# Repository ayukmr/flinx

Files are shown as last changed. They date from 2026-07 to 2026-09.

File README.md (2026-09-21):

# flinx



nRF52833-based low-profile 40% keyboard.

The board uses Kailh Choc V2 switches, and purposely doesn't include any stabilizers.
The PCB fits directly inside the case and is mounted with four screws.
A USB-C port on the side is used for charging, and a switch turns the board on/off.
Once turned on, the keyboard pairs over Bluetooth to send keystrokes.

This is intended as a small board mostly for travel, and as a low-profile version of the Monokei Neko.

## Schematic



## PCB



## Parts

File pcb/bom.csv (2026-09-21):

Reference | Qty | Value | Footprint | DigiKey Part # | Link
ANT1 | 1 | 451-00001 | Project:45100001 | 451-00001CT-ND | https://www.digikey.com/en/products/detail/ezurio/451-00001/9489361
C1 | 1 | 12 pF | Capacitor_SMD:C_0603_1608Metric | 311-1059-1-ND | https://www.digikey.com/en/products/detail/yageo/CC0603JRNPO9BN120/302793
C2 | 1 | 10 pF | Capacitor_SMD:C_0603_1608Metric | 311-4025-1-ND | https://www.digikey.com/en/products/detail/yageo/CC0603KRNPO9BN100/5883701
C3 | 1 | 100 nF | Capacitor_SMD:C_0603_1608Metric | 311-1343-1-ND | https://www.digikey.com/en/products/detail/yageo/CC0603ZRY5V9BB104/2103081
C4,C5,C6 | 3 | 10 uF | Capacitor_SMD:C_0603_1608Metric | 311-1781-1-ND | https://www.digikey.com/en/products/detail/yageo/CC0603KRX5R5BB106/5195190
D1,D2,D3,D4,D5,D6,D7,D8,D9,D10,D11,D12,D13,D14,D15,D16,D17,D18,D19,D20,D21,D22,D23,D24,D25,D26,D27,D28,D29,D30,D31,D32,D33,D34,D35,D36,D37,D38,D39,D40,D41,D42,D43,D44,D45,D46,D47,D48 | 48 | D | Diode_SMD:D_SOD-523 | 1655-1N4148WCT-ND | https://www.digikey.com/en/products/detail/smc-diode-solutions/1N4148W/6022450
J1 | 1 | USB_C_Receptacle_USB2.0_14P | Connector_USB:USB_C_Receptacle_JAE_DX07S016JA1R1500 | 670-DX07S016JA3R1500CT-ND | https://www.digikey.com/en/products/detail/jae-electronics/DX07S016JA3R1500/12354006
R1,R2 | 2 | 22 Ω | Resistor_SMD:R_0603_1608Metric | 311-22.0HRCT-ND | https://www.digikey.com/en/products/detail/yageo/RC0603FR-0722RL/727055
R3,R4 | 2 | 5.1k Ω | Resistor_SMD:R_0603_1608Metric | 311-5.10KHRCT-ND | https://www.digikey.com/en/products/detail/yageo/RC0603FR-075K1L/727268
R6 | 1 | 75k Ω | Resistor_SMD:R_0603_1608Metric | 311-75.0KHRCT-ND | https://www.digikey.com/en/products/detail/yageo/RC0603FR-0775KL/727378
R7 | 1 | 10k Ω | Resistor_SMD:R_0603_1608Metric | 311-10.0KHRCT-ND | https://www.digikey.com/en/products/detail/yageo/RC0603FR-0710KL/726880
SW49 | 1 | SW_SPDT | Project:SW_EG1215AA | EG5720CT-ND | https://www.digikey.com/en/products/detail/e-switch/EG1215AA/9559277
U1 | 1 | TP4057 | Package_TO_SOT_SMD:TSOT-23-6 | 4518-TP4057CT-ND | https://www.digikey.com/en/products/detail/umw/TP4057/17635237
Y1 | 1 | 32.768 kHz 9 pF | Crystal:Crystal_SMD_MicroCrystal_CC7V-T1A-2Pin_3.2x1.5mm_HandSoldering | 2195-CC7V-T1A-32.768KHZ-9PF-20PPM-TB-QACT-ND | https://www.digikey.com/en/products/detail/micro-crystal-ag/CC7V-T1A-32-768KHZ-9PF-20PPM-TB-QA/10499111

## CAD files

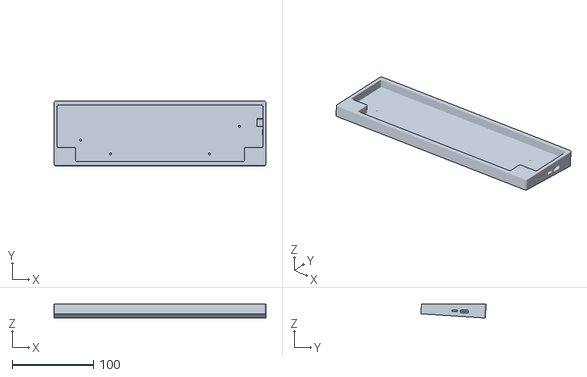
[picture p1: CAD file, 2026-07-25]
case/case.stl
261.1 x 80.5 x 17.3

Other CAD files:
case/case.f3d

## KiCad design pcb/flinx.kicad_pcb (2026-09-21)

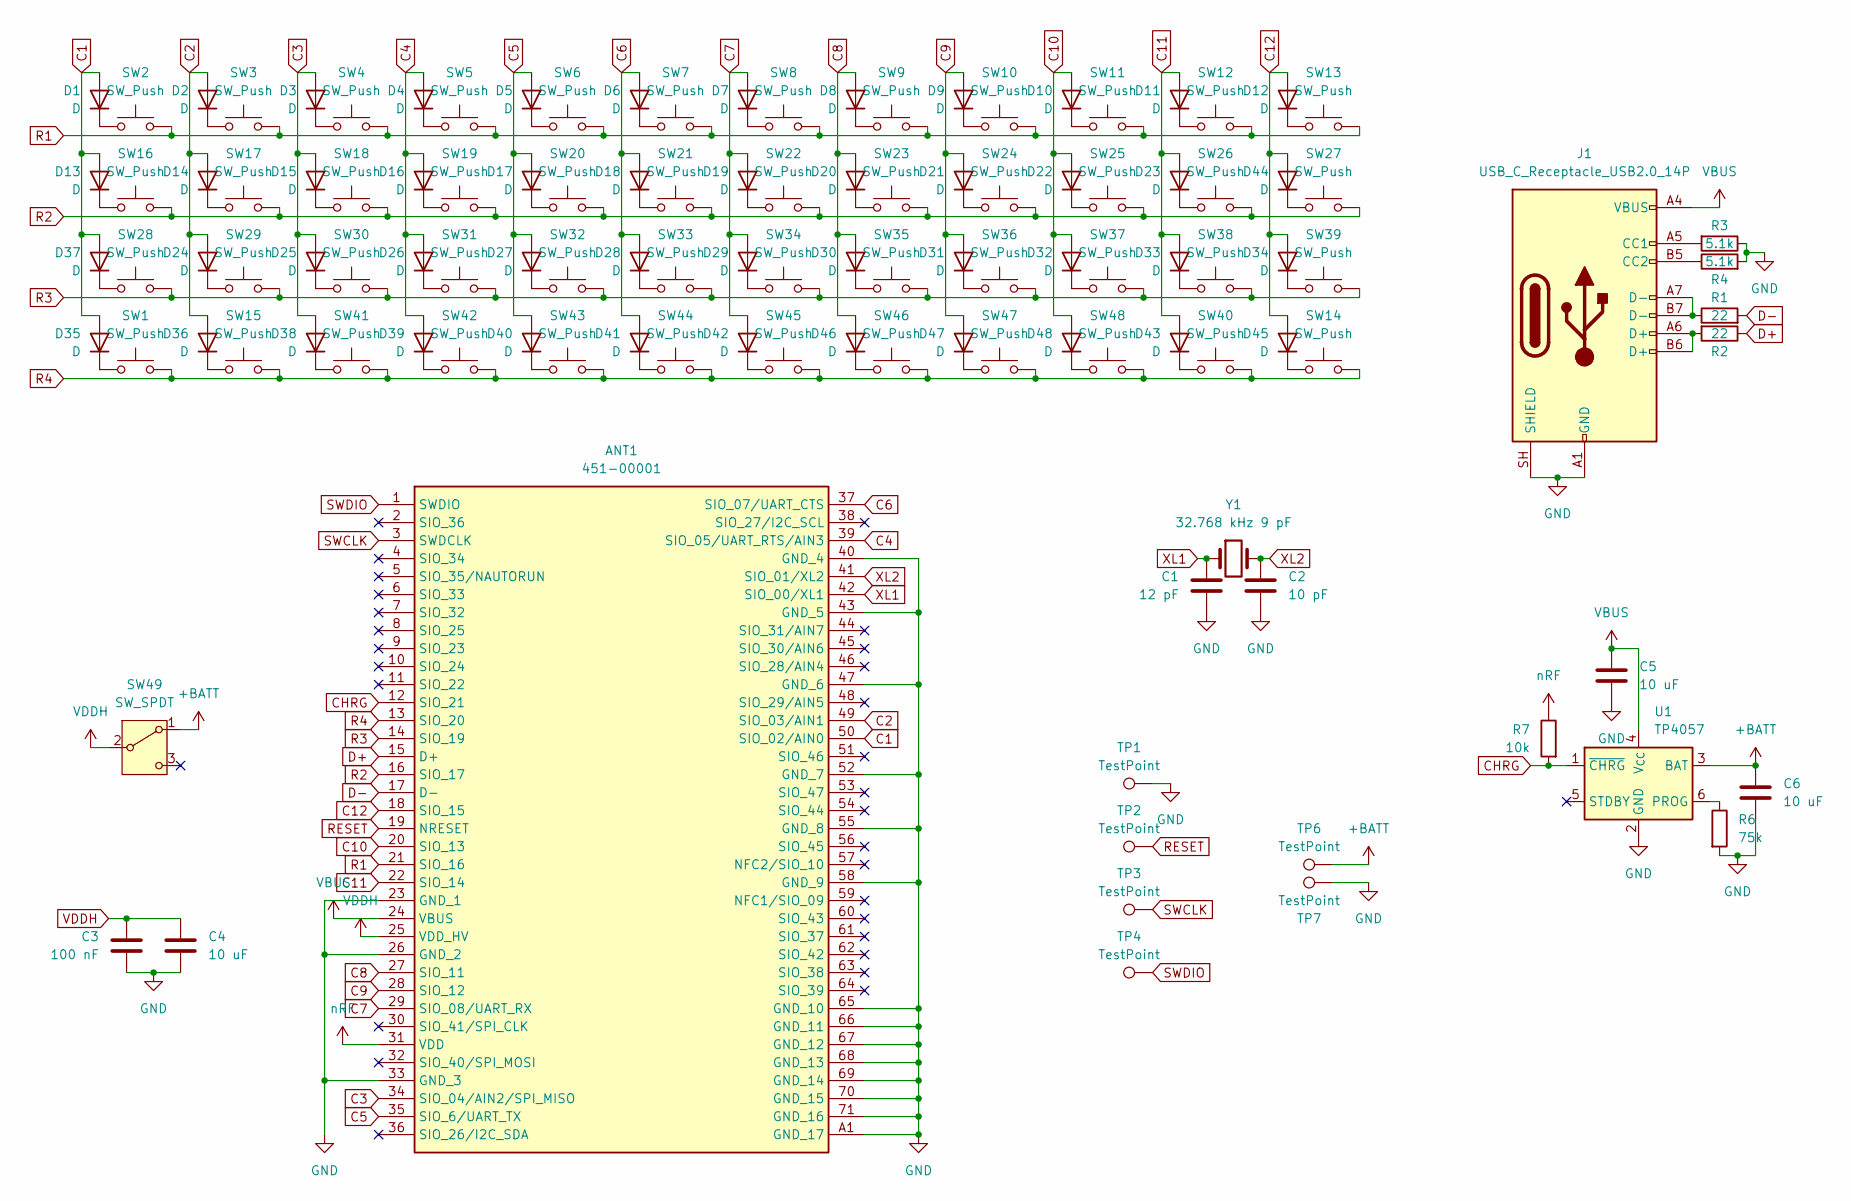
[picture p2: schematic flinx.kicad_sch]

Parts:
ANT1: 451-00001; 45100001; Manufacturer_Part_Number 451-00001; Mouser Part Number 814-451-00001
C1: 12 pF; C_0603_1608Metric
C2: 10 pF; C_0603_1608Metric
C3: 100 nF; C_0603_1608Metric
C4, C5, C6: 10 uF; C_0603_1608Metric
D1, D2, D3, D4, D5, D6, D7, D8, D9, D10, D11, D12, D13, D14, D15, D16, D17, D18, D19, D20, D21, D22, D23, D24, D25, D26, D27, D28, D29, D30, D31, D32, D33, D34, D35, D36, D37, D38, D39, D40, D41, D42, D43, D44, D45, D46, D47, D48: D; D_SOD-523
J1: USB_C_Receptacle_USB2.0_14P; USB_C_Receptacle_JAE_DX07S016JA1R1500
R1, R2: 22; R_0603_1608Metric
R3, R4: 5.1k; R_0603_1608Metric
R6: 75k; R_0603_1608Metric
R7: 10k; R_0603_1608Metric
SW1, SW2, SW3, SW4, SW5, SW6, SW7, SW8, SW9, SW10, SW11, SW12, SW13, SW14, SW16, SW17, SW18, SW19, SW20, SW21, SW22, SW23, SW24, SW25, SW26, SW29, SW30, SW31, SW32, SW33, SW34, SW35, SW36, SW37, SW38, SW40, SW41, SW48: SW_Push; SW_Kailh_Choc_V2_1.00u
SW15, SW39, SW42, SW47: SW_Push; SW_Kailh_Choc_V2_1.25u
SW27, SW28, SW43, SW44, SW45, SW46: SW_Push; SW_Kailh_Choc_V2_1.75u
SW49: SW_SPDT; SW_EG1215AA
TP1, TP2, TP3, TP4, TP6, TP7: TestPoint; Pad_SMD_1.5x1.5
U1: TP4057; TSOT-23-6
Y1: 32.768 kHz 9 pF; Crystal_SMD_MicroCrystal_CC7V-T1A-2Pin_3.2x1.5mm_HandSolder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

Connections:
+BATT: C6.2, SW49.1 (A), TP6.1 (1_1), U1.3 (BAT)
C1: ANT1.50 (SIO_02/AIN0), D1.2 (A), D13.2 (A), D35.2 (A), D37.2 (A)
C2: ANT1.49 (SIO_03/AIN1), D2.2 (A), D14.2 (A), D24.2 (A), D36.2 (A)
C3: ANT1.34 (SIO_04/AIN2/SPI_MISO), D3.2 (A), D15.2 (A), D25.2 (A), D38.2 (A)
C4: ANT1.39 (SIO_05/UART_RTS/AIN3), D4.2 (A), D16.2 (A), D26.2 (A), D39.2 (A)
C5: ANT1.35 (SIO_6/UART_TX), D5.2 (A), D17.2 (A), D27.2 (A), D40.2 (A)
C6: ANT1.37 (SIO_07/UART_CTS), D6.2 (A), D18.2 (A), D28.2 (A), D41.2 (A)
C7: ANT1.29 (SIO_08/UART_RX), D7.2 (A), D19.2 (A), D29.2 (A), D42.2 (A)
C8: ANT1.27 (SIO_11), D8.2 (A), D20.2 (A), D30.2 (A), D46.2 (A)
C9: ANT1.28 (SIO_12), D9.2 (A), D21.2 (A), D31.2 (A), D47.2 (A)
C10: ANT1.20 (SIO_13), D10.2 (A), D22.2 (A), D32.2 (A), D48.2 (A)
C11: ANT1.22 (SIO_14), D11.2 (A), D23.2 (A), D33.2 (A), D43.2 (A)
C12: ANT1.18 (SIO_15), D12.2 (A), D34.2 (A), D44.2 (A), D45.2 (A)
CHRG: ANT1.12 (SIO_21), R7.2, U1.1 (~CHRG)
D+: ANT1.15 (D+), R2.1
D-: ANT1.17 (D-), R1.2
GND: ANT1.23 (GND_1), ANT1.26 (GND_2), ANT1.33 (GND_3), ANT1.40 (GND_4), ANT1.43 (GND_5), ANT1.47 (GND_6), ANT1.52 (GND_7), ANT1.55 (GND_8), ANT1.58 (GND_9), ANT1.65 (GND_10), ANT1.66 (GND_11), ANT1.67 (GND_12), ANT1.68 (GND_13), ANT1.69 (GND_14), ANT1.70 (GND_15), ANT1.71 (GND_16), ANT1.A1 (GND_17), C1.2, C2.2, C3.1, C4.1, C5.2, C6.1, J1.A1 (GND), J1.A12 (GND), J1.B1 (GND), J1.B12 (GND), J1.SH (SHIELD), R3.1, R4.2, R6.2, TP1.1 (1_1), TP7.1 (1_1), U1.2 (GND)
unnamed: D1.1 (K), SW2.1
unnamed: D2.1 (K), SW3.1
unnamed: D3.1 (K), SW4.1
unnamed: D4.1 (K), SW5.1
unnamed: D5.1 (K), SW6.1
unnamed: D6.1 (K), SW7.1
unnamed: D7.1 (K), SW8.1
unnamed: D8.1 (K), SW9.1
unnamed: D9.1 (K), SW10.1
unnamed: D10.1 (K), SW11.1
unnamed: D11.1 (K), SW12.1
unnamed: D12.1 (K), SW13.1
unnamed: D13.1 (K), SW16.1
unnamed: D14.1 (K), SW17.1
unnamed: D15.1 (K), SW18.1
unnamed: D16.1 (K), SW19.1
unnamed: D17.1 (K), SW20.1
unnamed: D18.1 (K), SW21.1
unnamed: D19.1 (K), SW22.1
unnamed: D20.1 (K), SW23.1
unnamed: D21.1 (K), SW24.1
unnamed: D22.1 (K), SW25.1
unnamed: D23.1 (K), SW26.1
unnamed: D24.1 (K), SW29.1
unnamed: D25.1 (K), SW30.1
unnamed: D26.1 (K), SW31.1
unnamed: D27.1 (K), SW32.1
unnamed: D28.1 (K), SW33.1
unnamed: D29.1 (K), SW34.1
unnamed: D30.1 (K), SW35.1
unnamed: D31.1 (K), SW36.1
unnamed: D32.1 (K), SW37.1
unnamed: D33.1 (K), SW38.1
unnamed: D34.1 (K), SW39.1
unnamed: D35.1 (K), SW1.1
unnamed: D36.1 (K), SW15.1
unnamed: D37.1 (K), SW28.1
unnamed: D38.1 (K), SW41.1
unnamed: D39.1 (K), SW42.1
unnamed: D40.1 (K), SW43.1
unnamed: D41.1 (K), SW44.1
unnamed: D42.1 (K), SW45.1
unnamed: D43.1 (K), SW40.1
unnamed: D44.1 (K), SW27.1
unnamed: D45.1 (K), SW14.1
unnamed: D46.1 (K), SW46.1
unnamed: D47.1 (K), SW47.1
unnamed: D48.1 (K), SW48.1
unnamed: J1.A5 (CC1), R3.2
unnamed: J1.B5 (CC2), R4.1
unnamed: J1.A6 (D+), J1.B6 (D+), R2.2
unnamed: J1.A7 (D-), J1.B7 (D-), R1.1
unnamed: R6.1, U1.6 (PROG)
R1: ANT1.21 (SIO_16), SW2.2, SW3.2, SW4.2, SW5.2, SW6.2, SW7.2, SW8.2, SW9.2, SW10.2, SW11.2, SW12.2, SW13.2
R2: ANT1.16 (SIO_17), SW16.2, SW17.2, SW18.2, SW19.2, SW20.2, SW21.2, SW22.2, SW23.2, SW24.2, SW25.2, SW26.2, SW27.2
R3: ANT1.14 (SIO_19), SW28.2, SW29.2, SW30.2, SW31.2, SW32.2, SW33.2, SW34.2, SW35.2, SW36.2, SW37.2, SW38.2, SW39.2
R4: ANT1.13 (SIO_20), SW1.2, SW14.2, SW15.2, SW40.2, SW41.2, SW42.2, SW43.2, SW44.2, SW45.2, SW46.2, SW47.2, SW48.2
RESET: ANT1.19 (NRESET), TP2.1 (1_1)
SWCLK: ANT1.3 (SWDCLK), TP3.1 (1_1)
SWDIO: ANT1.1 (SWDIO), TP4.1 (1_1)
VBUS: ANT1.24 (VBUS), C5.1, J1.A4 (VBUS), J1.A9 (VBUS), J1.B4 (VBUS), J1.B9 (VBUS), U1.4 (V_{CC})
VDDH: ANT1.25 (VDD_HV), C3.2, C4.2, SW49.2 (B)
XL1: ANT1.42 (SIO_00/XL1), C1.1, Y1.1
XL2: ANT1.41 (SIO_01/XL2), C2.1, Y1.2
nRF: ANT1.31 (VDD), R7.1

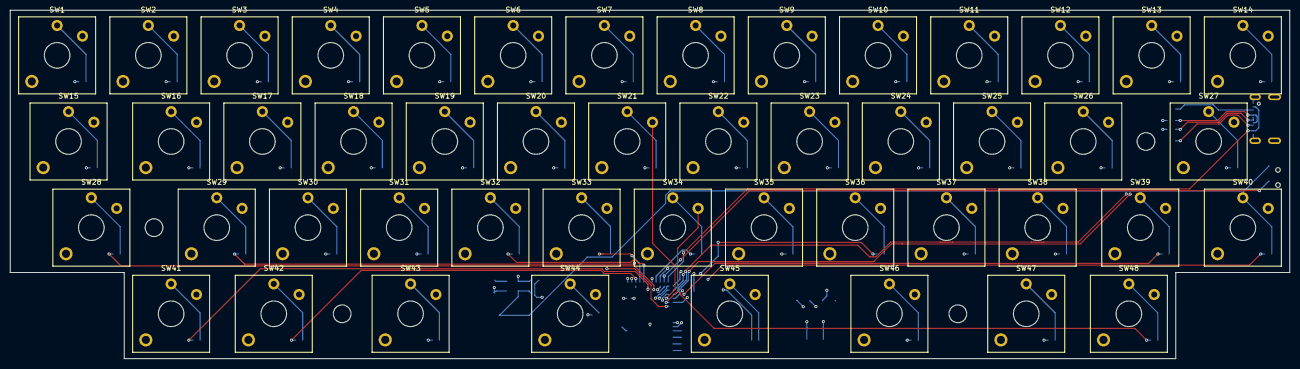
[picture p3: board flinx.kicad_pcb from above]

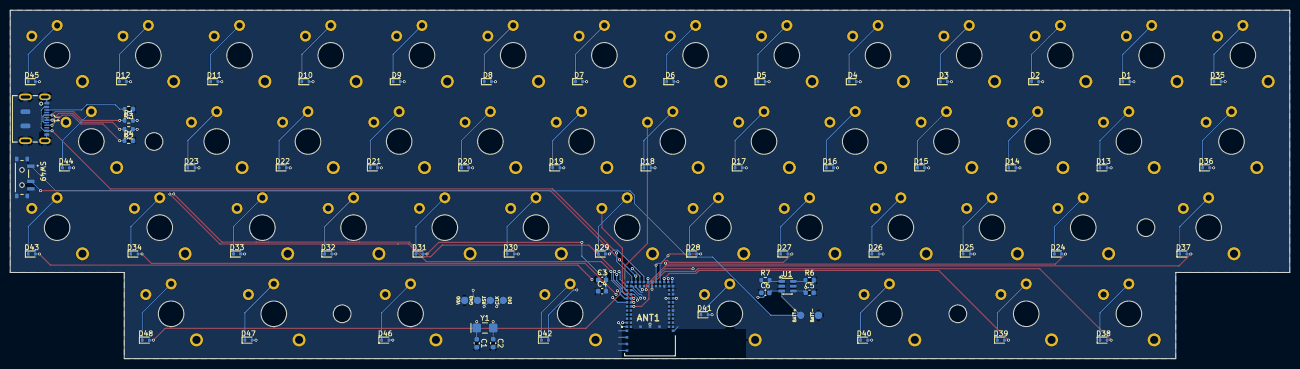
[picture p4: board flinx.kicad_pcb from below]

Board: 4 copper layers, 252.5 x 68.8 mm, 119 parts (71 on the bottom side), 82 nets.

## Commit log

2026-07-13 Initialize repo
    [flinx.kicad_pcb, flinx.kicad_sch]
2026-07-21 Add BOM
    [bom.csv]
2026-07-25 Update PCB
    [flinx.kicad_pcb, flinx.kicad_sch]
2026-07-25 Add case files
    [case.f3d, case.stl]
2026-09-21 Swap to BL654
    [bom.csv, flinx.kicad_pcb, flinx.kicad_sch]
2026-09-21 Move decoupling caps
    [flinx.kicad_pcb, flinx.kicad_sch]
